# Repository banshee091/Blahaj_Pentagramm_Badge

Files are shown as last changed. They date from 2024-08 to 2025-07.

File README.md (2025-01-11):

# Blahaj_Pentagramm_Badge

Firmware:

Build WLED (https://github.com/Aircoookie/WLED) using PlatformIO with the following Environment using the Buildflags for BME280 and PIR:

```
[env:d1_mini]
...
build_flags = ${common.build_flags_esp8266} -D USERMOD_BME280 -D USERMOD_PIRSWITCH -D PIR_SENSOR_PIN=13
...
```

Configuration:
```
LED Preferences: 
    -> Length = 15
    -> GPIO = 14
Usermods:
    -> SDA = 4
    -> SCL = 5
    -> Enabled

    Reboot
```

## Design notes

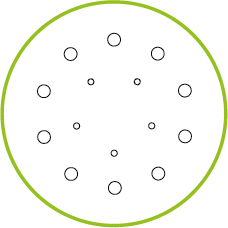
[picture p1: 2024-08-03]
Artwork/SilverFont/LED_placement.png

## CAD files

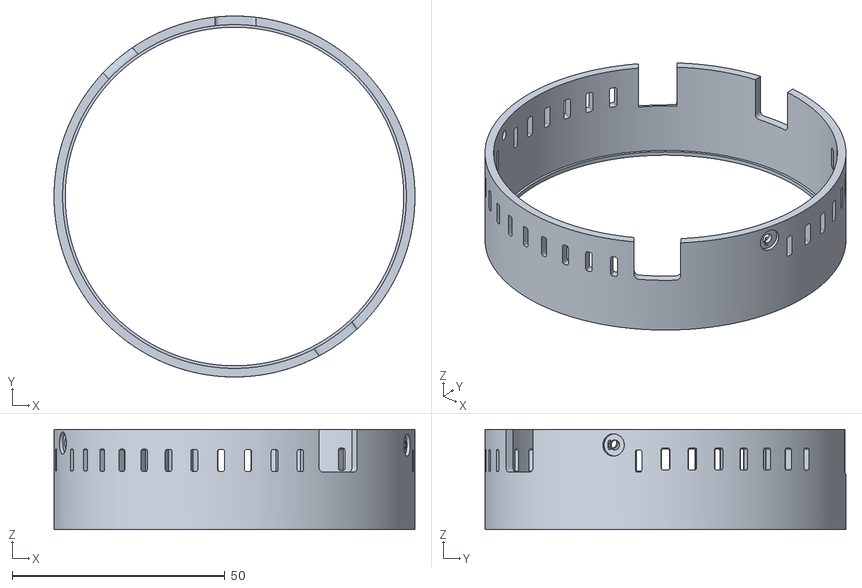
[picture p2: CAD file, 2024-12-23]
Case/STL/CaseV2_2.stl
84.8 x 84.8 x 23.5

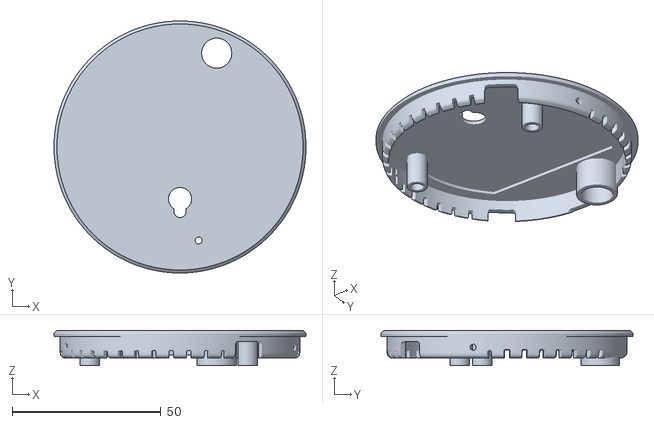
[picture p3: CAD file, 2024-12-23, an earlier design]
Case/STL/CaseV2_1.stl
84.8 x 84.8 x 11.8

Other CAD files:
Artwork/SilverFont/LED_Placement.dxf

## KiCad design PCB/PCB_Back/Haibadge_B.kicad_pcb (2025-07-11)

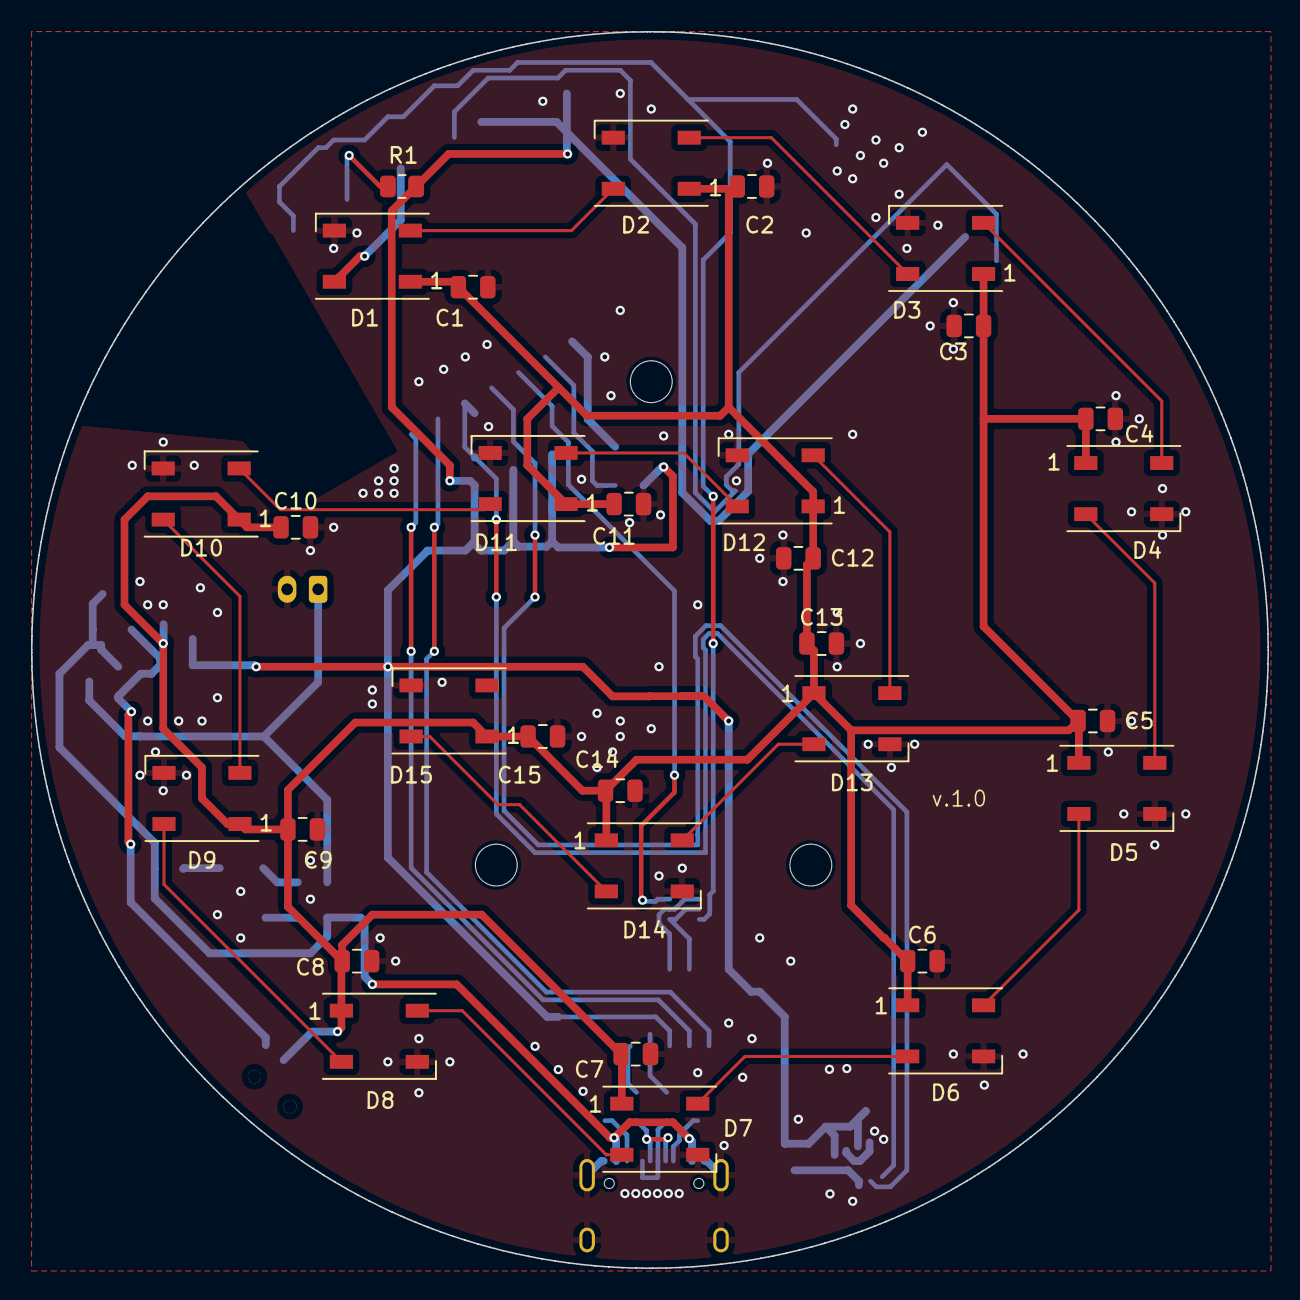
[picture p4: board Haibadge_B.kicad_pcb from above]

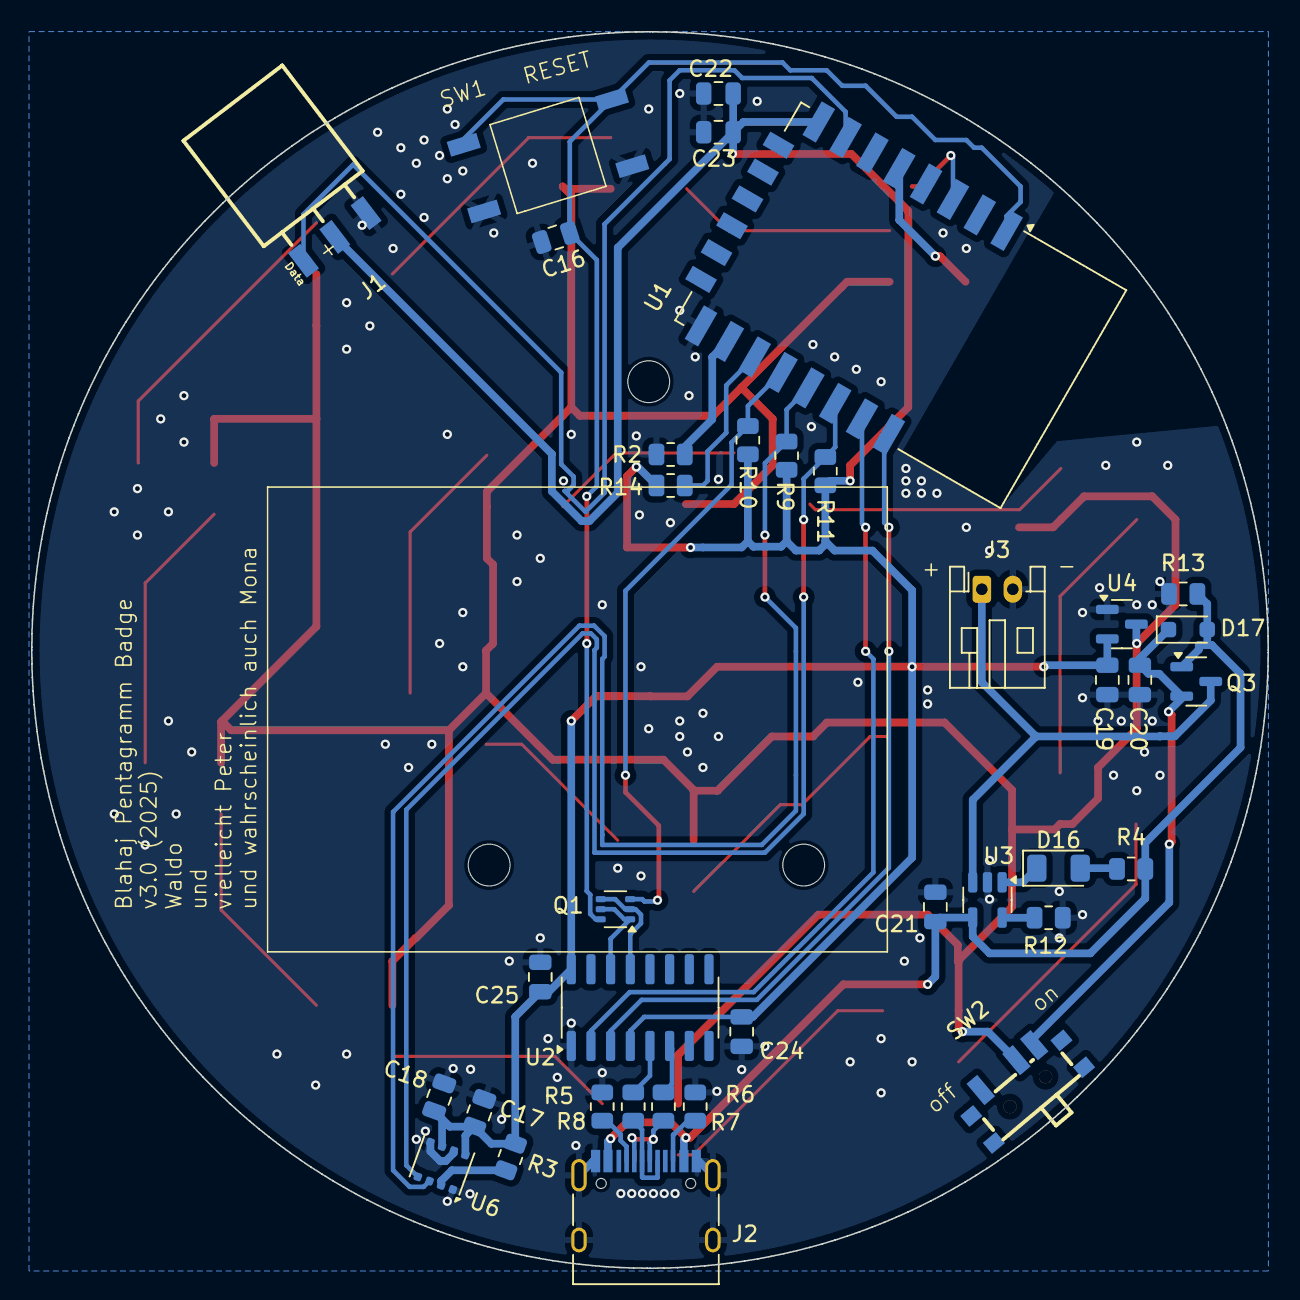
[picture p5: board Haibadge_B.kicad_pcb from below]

Board: 2 copper layers, 79.8 x 79.8 mm, 71 parts (37 on the bottom side), 43 nets.

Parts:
C1, C2, C3, C4, C5, C6, C7, C8, C9, C10, C11, C12, C13, C14, C15, C16, C17, C18, C22, C24, C25: 100nF; C_0805_2012Metric
C19, C20, C23: 1uF; C_0805_2012Metric
C21: 4.7uF; C_0805_2012Metric
D1, D2, D3, D4, D5, D6, D7, D8, D9, D10, D11, D12, D13, D14, D15: WS2812B; LED_WS2812B_PLCC4_5.0x5.0mm_P3.2mm
D16: LED; LED_1206_3216Metric
D17: D; D_SOD-323_HandSoldering
H1, H2, H3: MountingHole; MountingHole_2.7mm_M2.5
J1: Sensor connector; HDR-SMD_3P-P2.54-H-F-L11.5
J2: USB_C_Receptacle_USB2.0; USB_C_Receptacle_HRO_TYPE-C-31-M-12
J3: Lipo connector; JST_PH_S2B-PH-K_1x02_P2.00mm_Horizontal
Q1: UMH3N; SOT-363_SC-70-6
Q3: Q_PMOS_GSD; SOT-23
R1, R2, R3, R9, R10, R11, R13, R14: 10k; R_0805_2012Metric
R4, R12: 2k; R_0805_2012Metric
R5, R6: 5k1; R_0805_2012Metric
R7, R8: 22; R_0805_2012Metric
SW1: SW_Push_Dual; KH-6X6X6H-STM
SW2: SW_PWR; SW-SMD_MK-12C02-G025
U1: ESP-12E
U2: CH340C; SOIC-16_3.9x9.9mm_P1.27mm
U3: MCP73831-2-OT; SOT-23-5
U4: MCP1700x-330xxTT; SOT-23
U6: BME680; Bosch_LGA-8_3x3mm_P0.8mm_ClockwisePinNumbering

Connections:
+3V3: C17.1, C18.1, C19.1, C22.1, C23.1, C24.1, C25.1, J1.2, R1.1, R3.2, R9.2, R10.2, R11.2, R14.2, U1.8 (VCC), U2.4 (V3), U2.16 (VCC), U4.2 (VO), U6.6 (VDDIO), U6.8 (VDD)
+5V: C21.1, D17.2 (A), J2.A4 (VBUS), J2.A9 (VBUS), J2.B4 (VBUS), J2.B9 (VBUS), Q3.1 (G), R4.2, R13.2, U3.4 (V_{DD})
+BATT: J3.1, Q3.3 (D), U3.3 (V_{BAT})
/WS2812B/WS2812B: D1.4 (DIN), U1.5 (GPIO14)
/uC/D+: J2.A6 (D+), J2.B6 (D+), R8.2
/uC/D-: J2.A7 (D-), J2.B7 (D-), R7.1
/uC/RD+: R8.1, U2.5 (UD+)
/uC/RD-: R7.2, U2.6 (UD-)
DTR: Q1.2 (B1), Q1.4 (E2), U2.13 (~DTR)
GND: C1.2, C2.2, C3.2, C4.2, C5.2, C6.2, C7.2, C8.2, C9.2, C10.2, C11.2, C12.2, C13.2, C14.2, C15.2, C16.2, C17.2, C18.2, C19.2, C20.2, C21.2, C22.2, C23.2, C24.2, C25.2, D1.3 (VSS), D2.3 (VSS), D3.3 (VSS), D4.3 (VSS), D5.3 (VSS), D6.3 (VSS), D7.3 (VSS), D8.3 (VSS), D9.3 (VSS), D10.3 (VSS), D11.3 (VSS), D12.3 (VSS), D13.3 (VSS), D14.3 (VSS), D15.3 (VSS), J1.1, J2.A1 (GND), J2.A12 (GND), J2.B1 (GND), J2.B12 (GND), J2.S1 (SHIELD), J3.2, R2.2, R5.2, R6.1, R12.1, R13.1, SW1.3, SW1.4, U1.15 (GND), U2.1 (GND), U3.2 (V_{SS}), U4.1 (GND), U6.1 (GND), U6.5 (SDO), U6.7 (GND)
GPIO0: Q1.3 (C2), R10.1, U1.18 (GPIO0)
unnamed: D1.2 (DOUT), D2.4 (DIN)
unnamed: D2.2 (DOUT), D3.4 (DIN)
unnamed: D3.2 (DOUT), D4.4 (DIN)
unnamed: D4.2 (DOUT), D5.4 (DIN)
unnamed: D5.2 (DOUT), D6.4 (DIN)
unnamed: D6.2 (DOUT), D7.4 (DIN)
unnamed: D7.2 (DOUT), D8.4 (DIN)
unnamed: D8.2 (DOUT), D9.4 (DIN)
unnamed: D9.2 (DOUT), D10.4 (DIN)
unnamed: D10.2 (DOUT), D11.4 (DIN)
unnamed: D11.2 (DOUT), D12.4 (DIN)
unnamed: D12.2 (DOUT), D13.4 (DIN)
unnamed: D13.2 (DOUT), D14.4 (DIN)
unnamed: D14.2 (DOUT), D15.4 (DIN)
unnamed: D16.2 (A), R4.1
unnamed: D16.1 (K), U3.1 (STAT)
unnamed: C20.1, D17.1 (K), Q3.2 (S), SW2.3 (C)
unnamed: J2.A5 (CC1), R5.1
unnamed: J2.B5 (CC2), R6.2
unnamed: R1.2, U1.3 (EN)
unnamed: U1.22 (GPIO1/TXD), U2.3 (RXD)
unnamed: R14.1, U1.17 (GPIO2)
unnamed: U1.21 (GPIO3/RXD), U2.2 (TXD)
unnamed: R9.1, U1.19 (GPIO4), U6.3 (SDI)
unnamed: R11.1, U1.20 (GPIO5), U6.4 (SCK)
unnamed: R2.1, U1.16 (GPIO15)
unnamed: R12.2, U3.5 (PROG)
unnamed: R3.1, U6.2 (CSB)
RST: C16.1, Q1.6 (C1), SW1.1, SW1.2, U1.1 (~RST)
RTS: Q1.1 (E1), Q1.5 (B2), U2.14 (~RTS)
Sensor: J1.3, U1.7 (GPIO13)
VCC: C1.1, C2.1, C3.1, C4.1, C5.1, C6.1, C7.1, C8.1, C9.1, C10.1, C11.1, C12.1, C13.1, C14.1, C15.1, D1.1 (VDD), D2.1 (VDD), D3.1 (VDD), D4.1 (VDD), D5.1 (VDD), D6.1 (VDD), D7.1 (VDD), D8.1 (VDD), D9.1 (VDD), D10.1 (VDD), D11.1 (VDD), D12.1 (VDD), D13.1 (VDD), D14.1 (VDD), D15.1 (VDD), SW2.2 (B), U4.3 (VI)

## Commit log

2024-08-03 Layout, Routing, Stuff
    [Blahaj_Pentagramm_Badge_Front.kicad_pcb, Blahaj_Pentagramm_Badge_Front.kicad_sch, Haibadge_B.kicad_pcb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]
2024-08-04 Label placements, Misc Fixes, Partslist
    [Haibadge_B.kicad_pcb]
2024-08-09 Misc. Fixes, v1.0.
    [Haibadge_B.kicad_pcb, UC.kicad_sch]
2024-08-26 Added production Files
    [Haibadge_B-B_Courtyard.gbr, Haibadge_B-B_Cu.gbl, Haibadge_B-B_Fab.gbr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]
2024-09-02 Switched D+/D-, TX/RX, Switch Pins and rotated Lipo Marking
    [Haibadge_B.kicad_pcb, UC.kicad_sch]
2024-09-03 Moved Sensor Connector (make Room for Lipo) and Align with Pentagram Angle
    [Haibadge_B.kicad_pcb]
2024-09-07 Moved Sensor again (inset), Work on Case
    [Haibadge_B.kicad_pcb]
2024-09-07 Added R14 10k Pullup to GPIO2
    [Haibadge_B.kicad_pcb, UC.kicad_sch]
2024-09-08 Added Frontplate with Transparent Text and Silver Rim, Cleanup
    [Blahaj_Pentagramm_Badge_Front.kicad_pcb, Blahaj_Pentagramm_Badge_Front.kicad_sch, LED_Placement.dxf]
2024-09-08 Switched D16 Resistor from 1k to 2k
    [Blahaj_Pentagramm_Badge_Front.kicad_pcb, Blahaj_Pentagramm_Badge_Front.kicad_sch, Haibadge_B.kicad_pcb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]
2024-09-14 Change J1 to SMD, Production
    [Haibadge_B.kicad_pcb, UC.kicad_sch]
2024-09-26 Fixed Typo, added new ibom
    [Haibadge_B.kicad_pcb]
2024-09-30 Revert "Fixed Typo, added new ibom"
    This reverts commit 21eb23da6b9f4b1b78e37bb966b9e164ecd6150b.
    [Haibadge_B.kicad_pcb]
2024-12-23 Added STL
    [CaseV2_1.stl, CaseV2_2.stl]
2025-02-11 Added Plus for Sensor
    [Haibadge_B.kicad_pcb]
2025-02-21 Revert "WIP"
    This reverts commit bec9596e63e47101addb2355b0aaca8e1697c271.
    [Blahaj_Pentagramm_Badge_Front.kicad_pcb, Blahaj_Pentagramm_Badge_Front.kicad_sch]
2025-03-29 Production Samples
    TODO: Border for working sample to narrow.
    [Blahaj_Pentagramm_Badge_Front.kicad_pcb, Blahaj_Pentagramm_Badge_Front_Cyber.kicad_pcb]
2025-04-01 Back corrections, Front Edge Cut bigger.
    [Blahaj_Pentagramm_Badge_Front-Edge_Cuts.gbr, Blahaj_Pentagramm_Badge_Front-F_Cu.gbr, Blahaj_Pentagramm_Badge_Front-F_Mask.gbr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]
2025-07-11 Production ready commit
    Production Version 3 commit
    [Blahaj_Pentagramm_Badge_Front-Edge_Cuts.gbr, Blahaj_Pentagramm_Badge_Front-F_Cu.gbr, Blahaj_Pentagramm_Badge_Front-F_Mask.gbr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]
